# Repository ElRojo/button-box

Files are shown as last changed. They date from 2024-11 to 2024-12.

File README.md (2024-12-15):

<center>
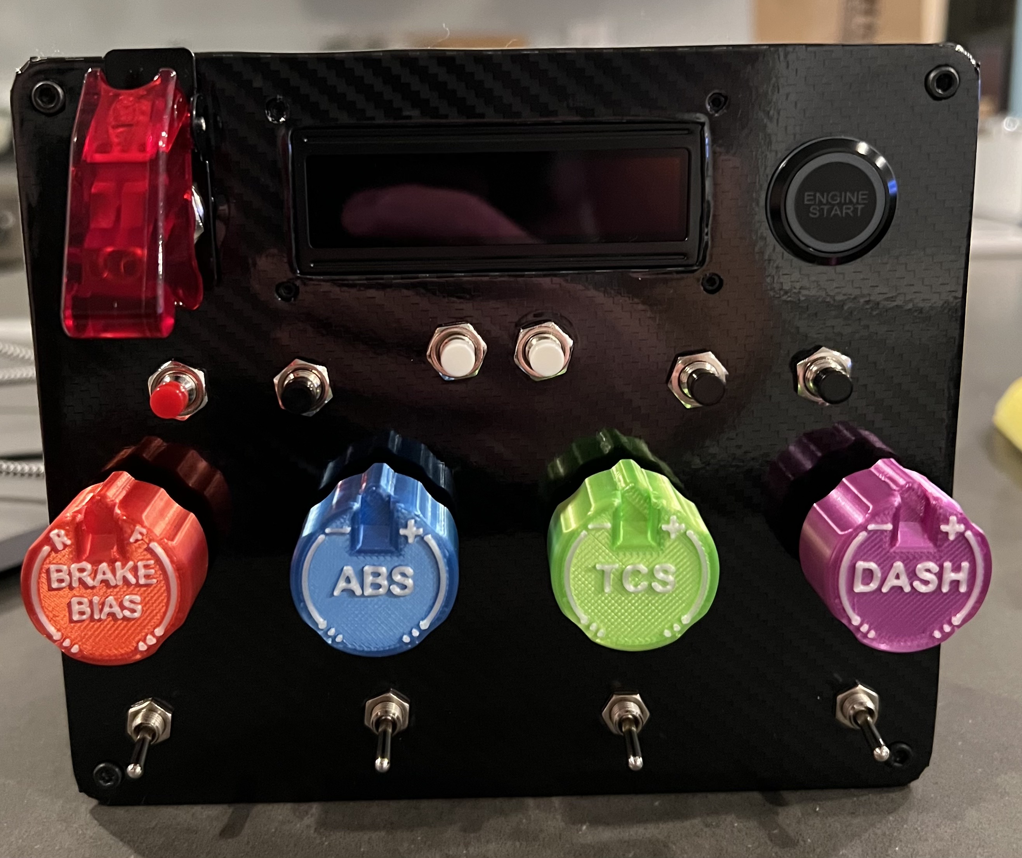
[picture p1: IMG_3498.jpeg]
Button Box

</center>
</br>

# Table of Contents

- [Purchase List](#purchase-list)
- [3D Files](#3d-files)
- [Lids](#lids)
- [16x2](#16x2-lids)
- [Box](#box)
- [Mounting Options](#mounting-options)

<center>
<b>
Click the Thumbnail for a How-To Video:
</b>
</br>
<kbd>
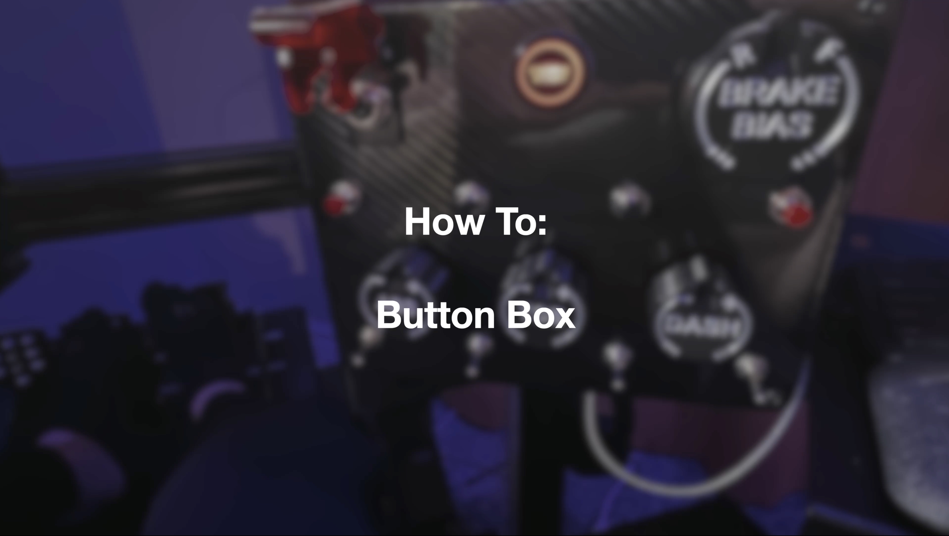
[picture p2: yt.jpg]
YouTube Video

</center>
</kbd>

## Purchase List

- [USB-C Pro Micro](https://a.co/d/40r7Z8c)
- [Toggle Switch with Aircraft Guard](https://a.co/d/8zprb8W)
- [Toggle Switches](https://a.co/d/gb6Z9sF)
- [Engine Start/Stop](https://a.co/d/4iWm9b6)
- [Diodes](https://a.co/d/17q5yrM)
- [Vinyl Wrap](https://a.co/d/8dlAxQy)
- [EC11 Rotary Encoders](https://a.co/d/904myFO)
- [12mm Momentary Switches](https://a.co/d/8DzCP9i)
- [7mm Momentary Switches](https://a.co/d/gAq71AI)
- [M3 Heat Set Inserts](https://a.co/d/5XJYXEE)
- [M3 assorted](https://a.co/d/9ft7rqe)
- [M6 assorted](https://a.co/d/cKX1Adg)
- [m6x60mm Bolts](https://a.co/d/dvMr3f9)

### 16x2 Option

- [Winstar OLED](https://www.aliexpress.us/item/2251832696798206.html)
- [I2C Adapter](https://a.co/d/55hU6gz)
- [Arduino Nano](https://a.co/d/cgAba1g): You can buy knockoffs... but make sure they at very least have a genuine CH340 chip.

# 3D Files

## Lids

After some experimenting I have found that having most of the toggle switches along the bottom is the most ergonomic, but you can populate it how you best see fit.

- [lid_7mm_switches](./3d%20files/lid_7mm_switches.stl): Lid that houses 7mm switches. Most holes are 6.3mm or 7mm here. Big brake bias knob works great here.

- [lid_12mm_switches](./3d%20files/lid_12mm_switches.stl): Lid that houses 12mm switches. Other holes are 6.3mm or 7mm here. Big brake bias knob works great here.

### 16x2 Lids

Allows for a 16x2 display. I used the OLED one linked in the purchase list. I haven't tried any others; so double check measurements if you decide to use an LCD instead.

Use an Arduino Nano to run the 16x2 display as the Pro Micro doesn't have any more space. However, you can add the two additional buttons to the Pro Micro matrix.

**There is a slight caveat with the displays**: Often times I need to restart SimHub or unplug/plug it in a few times to get the display to work correctly. I'm not sure if this is because of the Winstar display or an arduino / SimHub issue. But just be aware it's a bit finnicky.

- [lid_16x2_7mm_switches](./3d%20files/lid_16x2_7mm_switches.stl): This is the same as the 7mm switches, but has a cutout for an 16x2 display. It also moves one rotary from the top row back to the middle row.

- [lid_16x2_ctrls](./3d%20files/lid_16x2_ctrls.stl): Same as above, but this includes two additional button holes so you can use them to control the 16x2 screen (next/previous screens in SimHub).

### Knobs

The knobs are all the same size except for [BBKnob_large](./3d%20files/Knobs/BBKnob_large.stl). That knob is best used with lid_7mm_switches and lid_12mm_switches.

You don't have to use these, but I have found them to be quite nice. The original design is by [RCHeliGuy](https://www.thingiverse.com/thing:4673851).

## Box

The box has plenty of space for the items I have included in the purchase list. You'll notice it is akin to swiss cheese. I have given a lot of options for mounting for maximum flexibility.

The majority of the holes in the box are **6mm holes**.

There are also a few select **12mm holes** for running wire into the box if you do not want to panel mount or if you wish to run other wires into the box.

There are also holes for panel mounting your arduino pro micro / nano boards. You can find panel mounts here:

### Arduino Panel Mounts

- [Nano_PanelMount](./3d%20files/Nano_PanelMount.stl): Used to panel mount an Arduino Nano (USB Mini)
- [ProMicro_PanelMount-USBC](./3d%20files/ProMicro_PanelMount_USBC.stl): Used to panel mount most USBC pro micro boards
- [Arduino Pro-Micro Panel Mount](https://www.thingiverse.com/thing:4077845): Used for USB Micro Pro Micro Boards

## Mounting Options

Inside the [Mounting Folder](./3d%20files/Mounting/) there are multiple options for mounting; including simply attaching the box with 6mm bolts from inside the box (I have provided multiple holes to provide many options). It should also fit onto this [Button Box Mount by Advanced Sim Racing](https://www.advancedsimracing.com/products/button-box-mount)

If you want to use the hinge system: I recommend using little to no extensions, as the longer the extension, the more elasticity you'll have and it's not as sturdy. The best option is to mount it directly to a 4040/1515 profile. You'll also need the M6 x 60mm bolts linked in the purchase list.

- [4040-side-hinge](./3d%20files/Mounting/4040-side-hinge.stl): Used to connect any of the extensions to your 4040/1515 profile. This can be mounted horizontally or vertically along the profile.
- [box-side-hinge](./3d%20files/Mounting/box-side-hinge.stl): This attaches to the button box. Could be on the back or the sides. On the back, there are holes to attach this horizontally or vertically.
- [4040-to-box-connection](./3d%20files/Mounting/4040-to-box-connection.stl): This piece can be bolted to your 4040/1515 profile and then directly attached to the box-side-hinge.
- [Extensions](./3d%20files/Mounting/Extensions/): Varying lengths for extending the box from the 4040/1515 profiles.

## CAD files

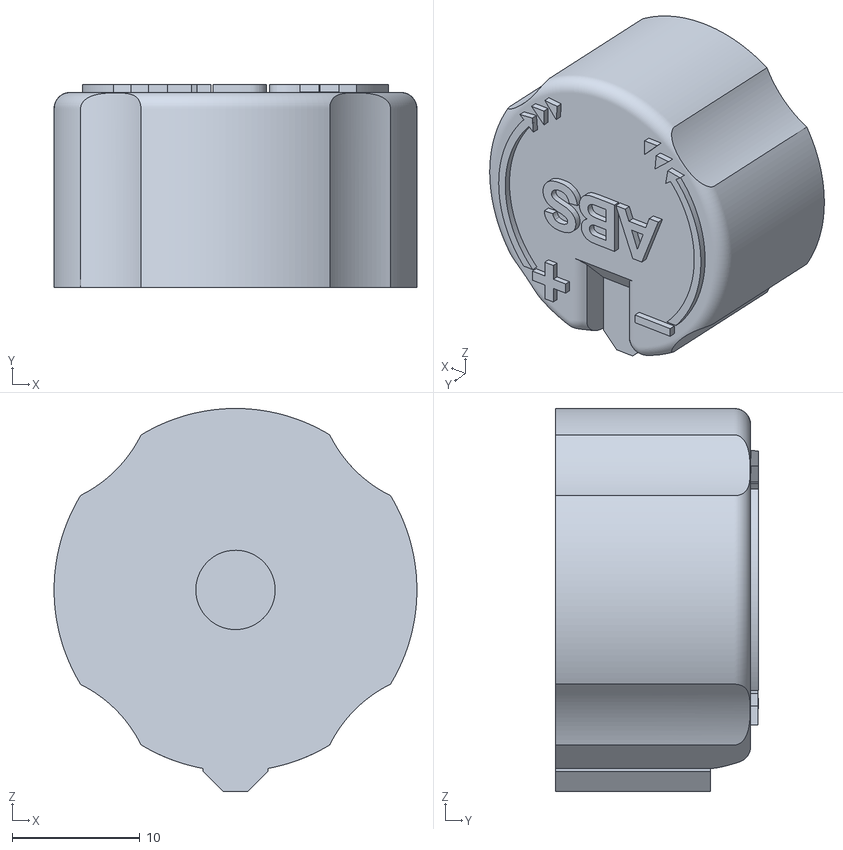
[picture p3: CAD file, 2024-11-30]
3d files/Knobs/ABSKnob.stl
28.3 x 15.9 x 29.9

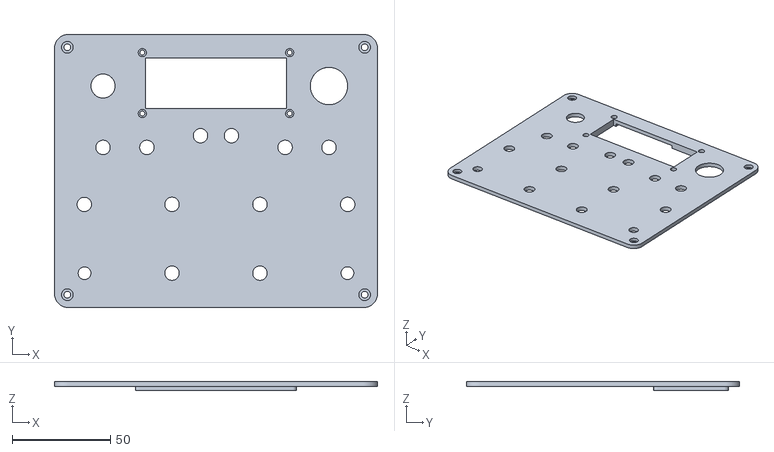
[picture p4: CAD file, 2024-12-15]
3d files/lid_16x2_ctrls.stl
164.4 x 139.0 x 4.80

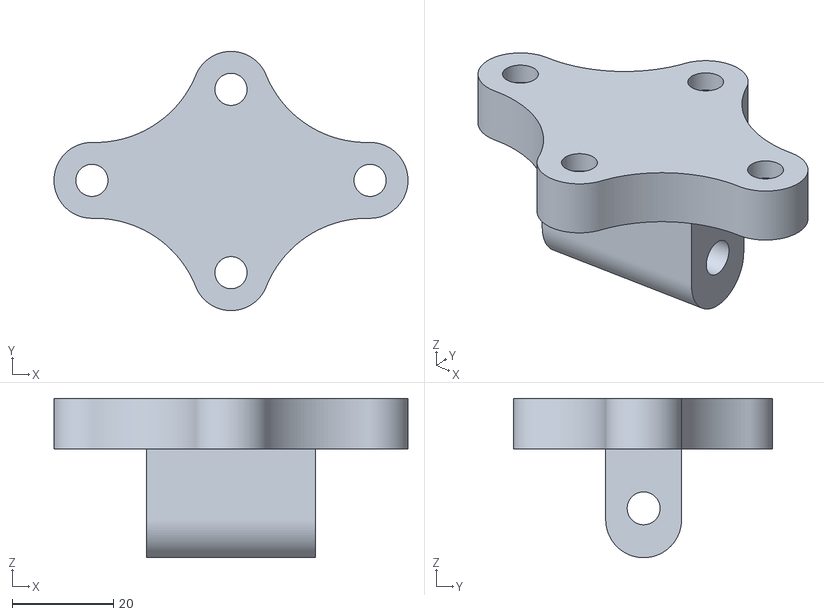
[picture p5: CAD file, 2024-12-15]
3d files/Mounting/4040-to-box-connection.stl
70.0 x 51.2 x 31.5

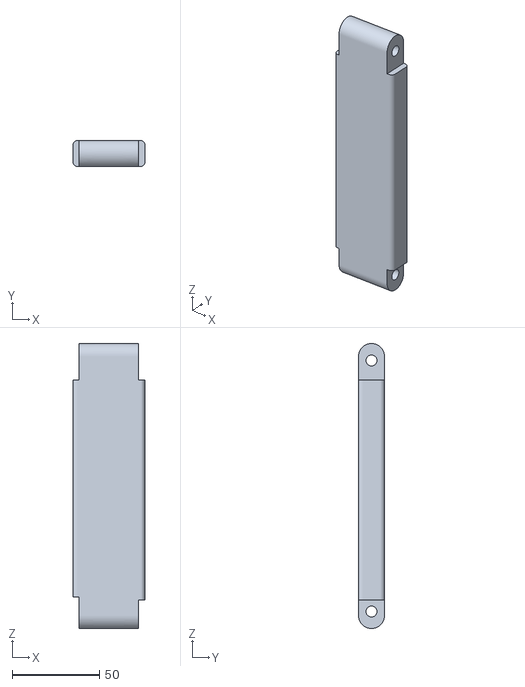
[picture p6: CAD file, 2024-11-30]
3d files/Mounting/Extensions/5-in-ext.stl
41.3 x 15.0 x 163.6

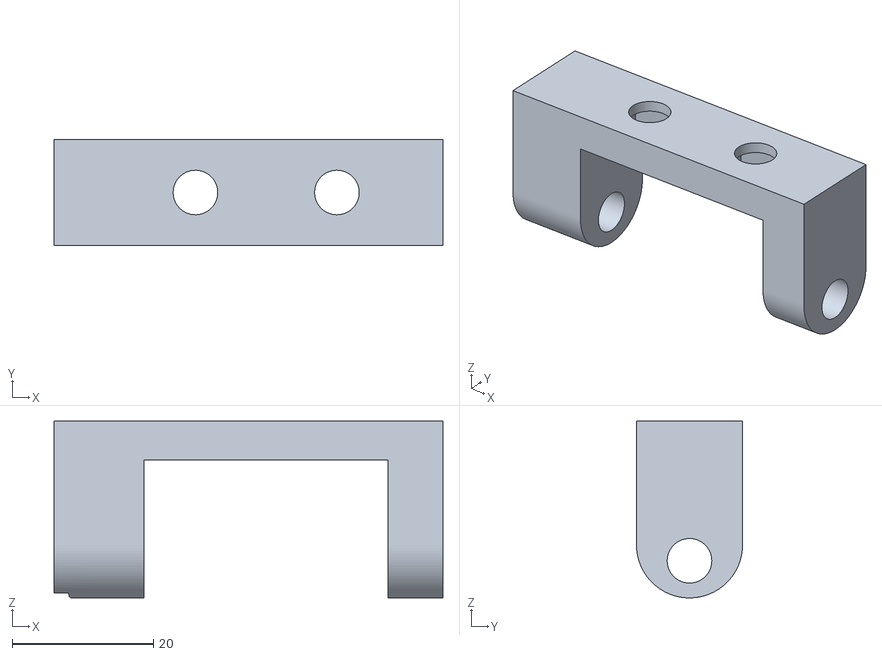
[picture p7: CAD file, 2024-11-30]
3d files/Mounting/box-side-hinge.stl
55.0 x 15.0 x 25.0

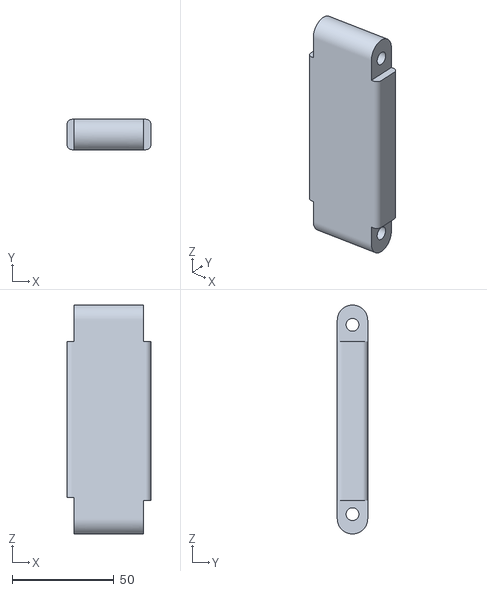
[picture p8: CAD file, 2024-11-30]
3d files/Mounting/Extensions/3-in-ext.stl
41.3 x 15.0 x 112.6

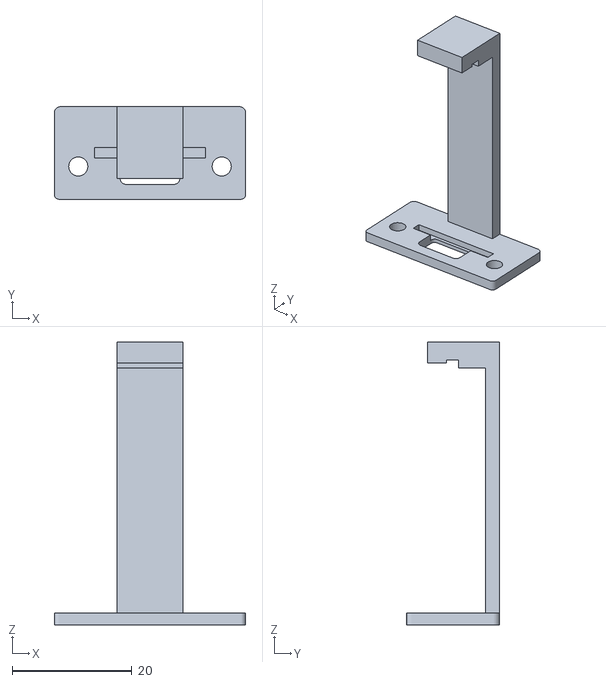
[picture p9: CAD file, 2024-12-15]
3d files/Nano_PanelMount.stl
32.0 x 15.5 x 47.3

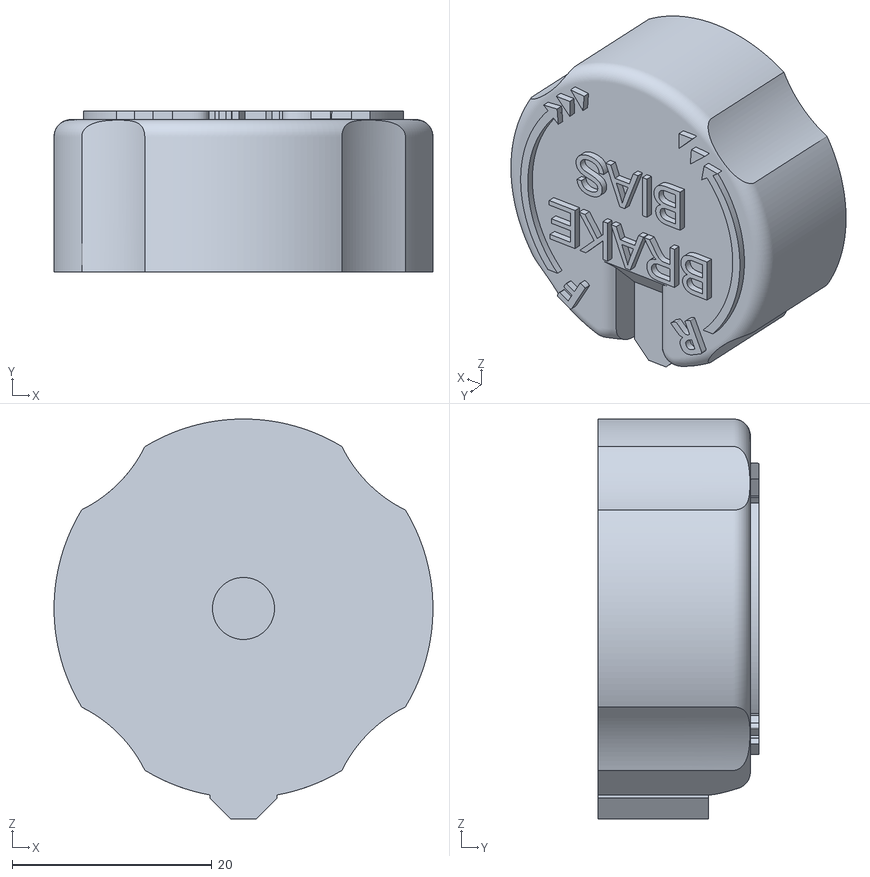
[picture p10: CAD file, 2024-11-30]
3d files/Knobs/BBKnob_large.stl
38.0 x 16.1 x 40.1

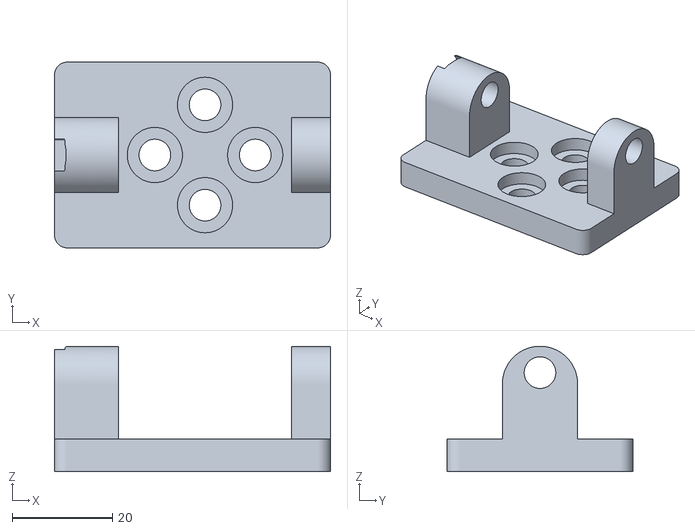
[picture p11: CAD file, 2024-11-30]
3d files/Mounting/4040-side-hinge.stl
55.0 x 37.0 x 25.0

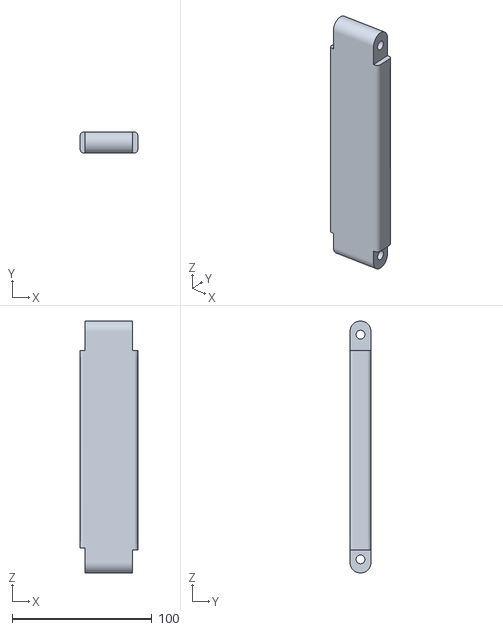
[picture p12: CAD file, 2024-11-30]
3d files/Mounting/Extensions/6_5-in-ext.stl
41.3 x 15.0 x 180.6

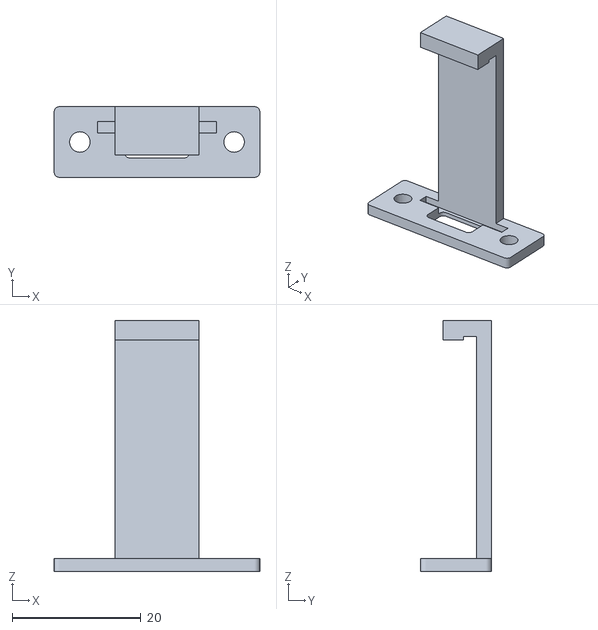
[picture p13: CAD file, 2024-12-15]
3d files/ProMicro_PanelMount_USBC.stl
32.0 x 11.0 x 39.0

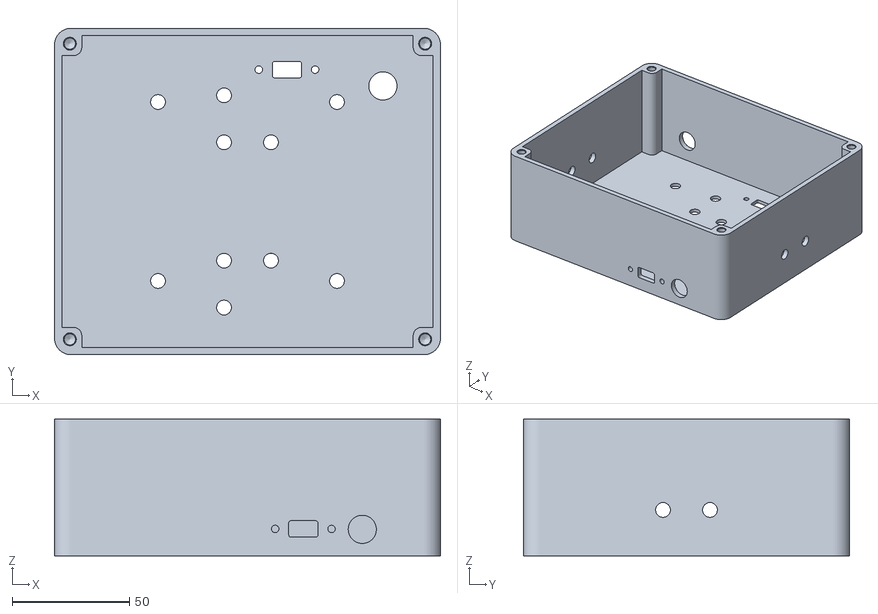
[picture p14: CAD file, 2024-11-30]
3d files/Box.stl
164.4 x 139.0 x 58.2

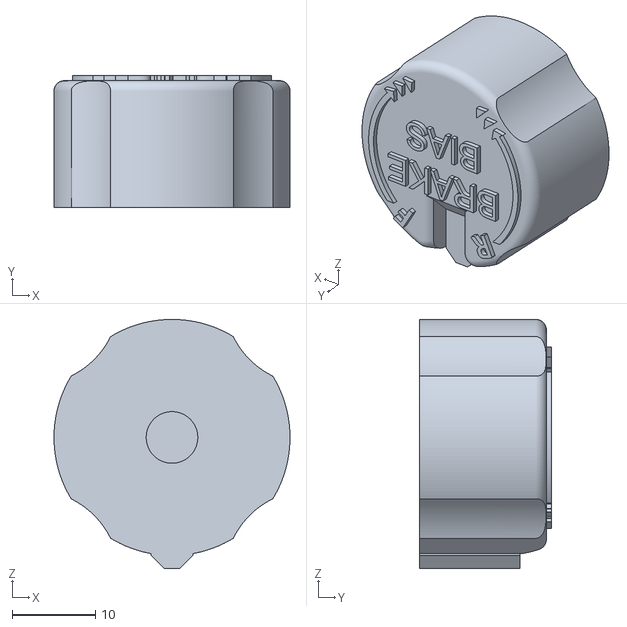
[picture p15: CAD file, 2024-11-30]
3d files/Knobs/BBKnob.stl
28.3 x 15.9 x 29.9

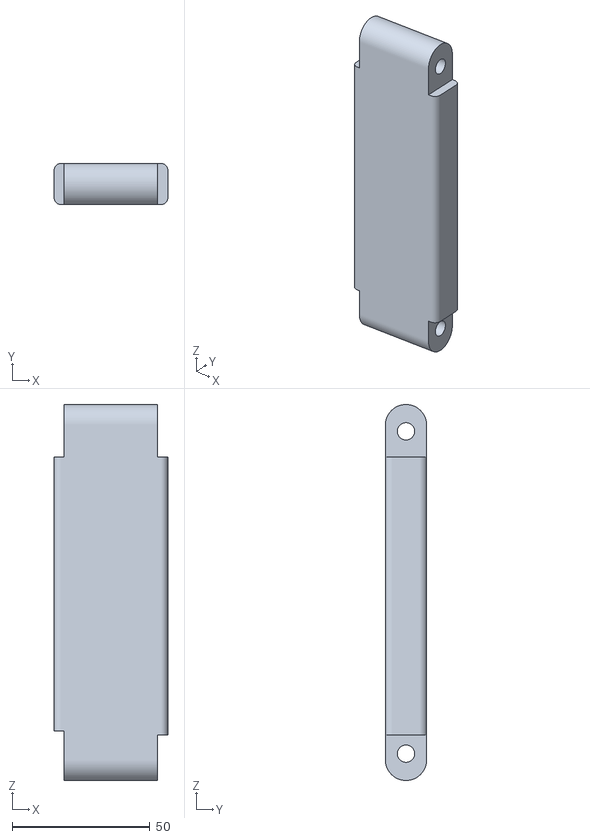
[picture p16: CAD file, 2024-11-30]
3d files/Mounting/Extensions/4-in-ext.stl
41.3 x 15.0 x 136.6

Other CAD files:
3d files/Knobs/TCSKnob.stl
3d files/Knobs/DashKnob.stl
3d files/lid_12mm_switches.stl
3d files/lid_7mm_switches.stl
3d files/lid_16x2_7mm_switches.stl

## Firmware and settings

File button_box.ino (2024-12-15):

// #define HALF_STEP // uncomment if using half-step encoders
#define ENABLE_PULLUPS // comment this line if using rotary encoders with built-in pull-ups

#include <Keypad.h>
#include <Joystick.h>

constexpr int NUMROTARIES = 4;
constexpr int NUMROWS = 4; // set rows here
constexpr int NUMCOLS = 4; // set columns here
constexpr int NUMBUTTONS = 16; // set button count here depending on matrix

// button matrix setup. update if numrows/numcols changes
const byte buttons[NUMROWS][NUMCOLS] = {
  {0, 1, 2, 3},
  {4, 5, 6, 7},
  {8, 9, 10, 11},
  {12, 13, 14, 15}
};

// arduino pins for rows and columns
byte rowPins[NUMROWS] = {21,20,19,18};
byte colPins[NUMCOLS] = {15,14,16,10};

struct RotaryEncoder {
  byte pin1;
  byte pin2;
  int ccwchar;
  int cwchar;
  volatile unsigned char state;
};

RotaryEncoder rotaries[NUMROTARIES] {
  {3, 2, 16, 17, 0},
  {5, 4, 18, 19, 0},
  {7, 6, 20, 21, 0},
  {9, 8, 22, 23, 0}
};


Keypad buttbx = Keypad( makeKeymap(buttons), rowPins, colPins, NUMROWS, NUMCOLS);
Joystick_ Joystick(JOYSTICK_DEFAULT_REPORT_ID,
  JOYSTICK_TYPE_JOYSTICK, 32, 0,
  false, false, false, false, false, false,
  false, false, false, false, false);

constexpr uint8_t DIR_CCW = 0x10;
constexpr uint8_t DIR_CW = 0x20;
constexpr uint8_t R_START = 0x0;

#ifdef HALF_STEP
constexpr uint8_t R_CCW_BEGIN = 0x1;
constexpr uint8_t R_CW_BEGIN = 0x2;
constexpr uint8_t R_START_M = 0x3;
constexpr uint8_t R_CW_BEGIN_M = 0x4;
constexpr uint8_t R_CCW_BEGIN_M = 0x5;
const unsigned char ttable[6][4] = {
  // R_START (00)
  {R_START_M,            R_CW_BEGIN,     R_CCW_BEGIN,  R_START},
  // R_CCW_BEGIN
  {R_START_M | DIR_CCW, R_START,        R_CCW_BEGIN,  R_START},
  // R_CW_BEGIN
  {R_START_M | DIR_CW,  R_CW_BEGIN,     R_START,      R_START},
  // R_START_M (11)
  {R_START_M,            R_CCW_BEGIN_M,  R_CW_BEGIN_M, R_START},
  // R_CW_BEGIN_M
  {R_START_M,            R_START_M,      R_CW_BEGIN_M, R_START | DIR_CW},
  // R_CCW_BEGIN_M
  {R_START_M,            R_CCW_BEGIN_M,  R_START_M,    R_START | DIR_CCW},
};
#else

constexpr uint8_t R_CW_BEGIN = 0x2;
constexpr uint8_t R_CW_FINAL = 0x1;
constexpr uint8_t R_CW_NEXT = 0x3;
constexpr uint8_t R_CCW_BEGIN = 0x4;
constexpr uint8_t R_CCW_FINAL = 0x5;
constexpr uint8_t R_CCW_NEXT = 0x6;
const unsigned char ttable[7][4] = {
  // R_START
  {R_START,    R_CW_BEGIN,  R_CCW_BEGIN, R_START},
  // R_CW_FINAL
  {R_CW_NEXT,  R_START,     R_CW_FINAL,  R_START | DIR_CW},
  // R_CW_BEGIN
  {R_CW_NEXT,  R_CW_BEGIN,  R_START,     R_START},
  // R_CW_NEXT
  {R_CW_NEXT,  R_CW_BEGIN,  R_CW_FINAL,  R_START},
  // R_CCW_BEGIN
  {R_CCW_NEXT, R_START,     R_CCW_BEGIN, R_START},
  // R_CCW_FINAL
  {R_CCW_NEXT, R_CCW_FINAL, R_START,     R_START | DIR_CCW},
  // R_CCW_NEXT
  {R_CCW_NEXT, R_CCW_FINAL, R_CCW_BEGIN, R_START},
};
#endif


void initEncoders() {
  for (int i = 0; i < NUMROTARIES; i++) {
    pinMode(rotaries[i].pin1, INPUT);
    pinMode(rotaries[i].pin2, INPUT);
    #ifdef ENABLE_PULLUPS
      digitalWrite(rotaries[i].pin1, HIGH);
      digitalWrite(rotaries[i].pin2, HIGH);
    #endif
  }
}

void checkAllButtons() {
    if (!buttbx.getKeys()) return;
        for (int i = 0; i < LIST_MAX; ++i) {
            if (!buttbx.key[i].stateChanged) continue;
                bool isPressed = (buttbx.key[i].kstate == PRESSED || buttbx.key[i].kstate == HOLD);
                Joystick.setButton(buttbx.key[i].kchar, isPressed);
    }
}

void checkAllEncoders(void) {
  for (int i = 0; i < NUMROTARIES; i++) {
    unsigned char result = processEncoder(i);
    if (result == DIR_CCW) {
      Joystick.setButton(rotaries[i].ccwchar, 1);
      delay(50);
      Joystick.setButton(rotaries[i].ccwchar, 0);
    };
    if (result == DIR_CW) {
      Joystick.setButton(rotaries[i].cwchar, 1);
      delay(50);
      Joystick.setButton(rotaries[i].cwchar, 0);
    };
  }
}

unsigned char processEncoder(int i) {
  unsigned char pinstate = (digitalRead(rotaries[i].pin2) << 1) | digitalRead(rotaries[i].pin1);
  rotaries[i].state = ttable[rotaries[i].state & 0xf][pinstate];
  return (rotaries[i].state & 0x30);
}

void setup() {
  Joystick.begin();
  initEncoders();
}

void loop() {
  checkAllEncoders();
  checkAllButtons();
}

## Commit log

2024-11-30 feat: button_box code
2024-11-30 feat: 3d files and readme
    [3-in-ext.stl, 4-in-ext.stl, 4040-hinge.stl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]
2024-12-15 chore: adding some files and updating ino
    [4040 Hinge Connector.stl, Nano_PanelMount.stl, NewBox_Shortest.stl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]
2024-12-15 fix: renaming and adding readme
    [3-in-ext.stl, 4-in-ext.stl, 4040-side-hinge.stl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]
